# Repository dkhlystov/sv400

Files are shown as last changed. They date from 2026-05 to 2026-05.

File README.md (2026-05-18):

# SUZUKI SV400

## Личные ощущения

#### Что понравилось

- Тянет достойно - L-мотор неприхотлив к оборотам. Тяга хорошая от низов до верха.

- Легкий и сбитый - аллюминиевая рама-клетка это тема. Вес небольшой, жесткость на высоте.

- Расход в пределах 5 л.

- Небольшие размеры - плюс в междурядье.

- Звук мотора хорош.

#### Хотелось бы улучшить

- На классике после 100 км/ч ветром сдувает, на "S" возможно не так .

- Высокий центр тяжести. В движении не парит, а вот когда стоишь - мот хочет упасть.

- Карбюраторы требуют внимания (не инжектор к сожалению).

- Нет ABS. Пару раз оттормаживался до срыва - ощущения не из приятных.

## Документация

[Руководство пользователя](https://github.com/dkhlystov/sv400/tree/main/Documentation/SV650%20User%20Manual) (по большей части SV400 и SV650 соответствуют)

[Руководство по обслуживанию SV650 1998](https://github.com/dkhlystov/sv400/tree/main/Documentation/SV650%20Service%20Manual/SV650%201998) (SV400 и SV650 1998 года соответстуют)

[Руководство по обслуживанию SV650 2003](https://github.com/dkhlystov/sv400/tree/main/Documentation/SV650%20Service%20Manual/SV650%202003) (SV650 2003 года более новый, возможно есть полезная инфа)

[Каталог запчастей SV400](https://github.com/dkhlystov/sv400/tree/main/Documentation/SV400%20Cat) (OEM номера)

## Современная приборка

Свой мот взял беспробежным, но в Японии была повреждена приборка. Промониторив рынок, решил взять с алика китайскую цифровую приборку для Titan 150. [Доки на нее есть в репе](https://github.com/dkhlystov/sv400/tree/main/Dashboard%20Controller/Titan%20150).

Крепление моделировал в sketch up. Заказал в конторе по лазерной резке. Дальше болгарка, сварка, краска.

Чтобы срастить железо с приборкой сделал контроллер.

Приборка Titan 150 сделана под тросик (скорость), поэтому пришлось разобрать ее и вывести провод от датчика холла.

Дополнительно есть возможность подключить индикатор передачи (не сильно большими трудозатратами). Не занимался пока этим.

На индикатор уровня топлива кинул датчик лампы (не нашел подходящих вариантов резистивных датчиков). На данный момент датчик топлива показывает два значения 100% и 20%.

Для тех, кто решит повторить - схемы "Splan", печатная плата "Sprint Layout", код "Arduino IDE"

#### Выводы

| Обозначение | Описание |
| - | - |
| GND | Общий |
| 12V | + 12 В |
| S+ | Питание датчика скорости |
| SO | Выход скорости (на Titan 150) |
| FO | Выход датчика топлива резистивный (на Titan 150) |
| SI | Вход датчика скорости с мота |
| FIA | Вход аналогового датчика топлива (лампы) с мота |
| FID | Вход цифрового датчика топлива (не тестил, просто добавил возможность подключить) |

Контроллер сделан на базе ESP12. Тесты и настройки доступны по Wi-Fi "SV400" (точка доступа отключается после 60 сек простоя).
Для входа используется адрес http://192.168.1.1

Есть вопросы - пиши на `dkhlystov@gmail.com`

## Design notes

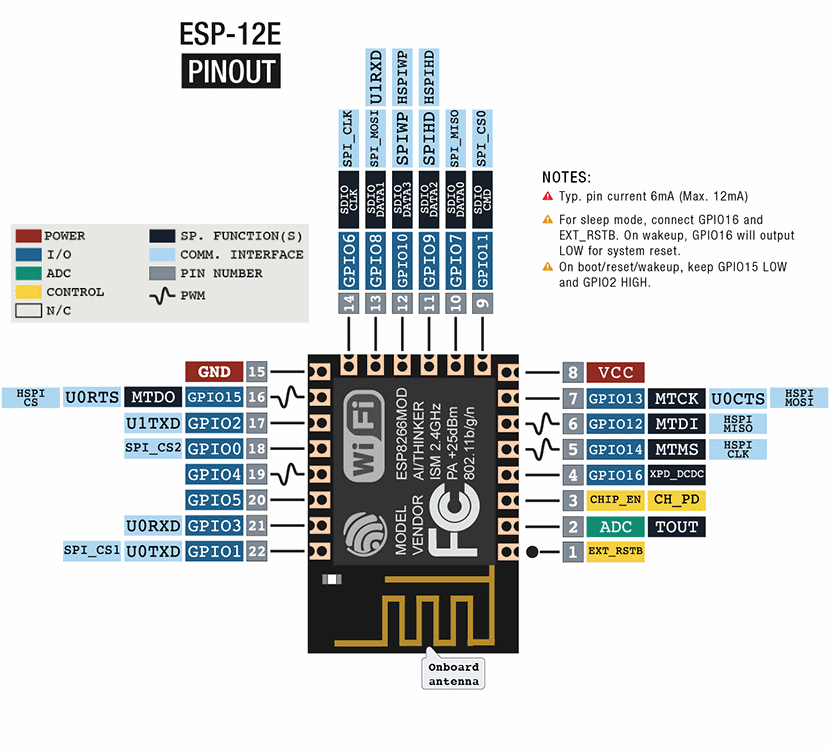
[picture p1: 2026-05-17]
Dashboard Controller/v4/tmp/62dd93cfcf3acb66be8b525c35198cde.png

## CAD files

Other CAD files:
Dashboard Controller/scheme.skp

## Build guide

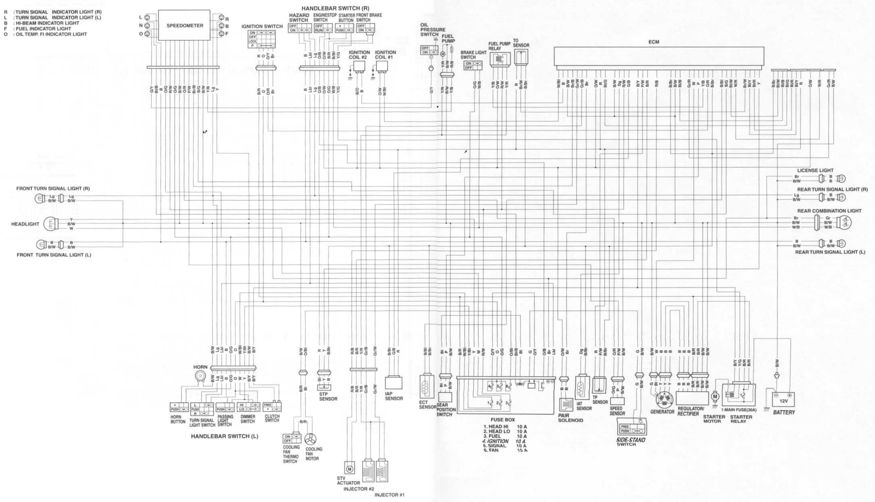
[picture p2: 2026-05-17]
Documentation/SV650 Service Manual/SV650 Wiring diagram.jpg

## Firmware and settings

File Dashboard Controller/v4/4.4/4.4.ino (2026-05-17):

#include <ArduinoJson.h>
#include <ESP8266WebServer.h>
#include <ESP8266WiFi.h>
#include <FileData.h>
#include <LittleFS.h>
#include "Dashboard.h"
#include "SpeedSensor.h"
#include "FuelSensorAnalog.h"
#include "FuelSensorDigital.h"

// === CONST ===
const int DASHBOARD_MODE_WORK = 0;
const int DASHBOARD_MODE_TEST = 1;
const int TIRE_120_60_R17 = 0;
const int TIRE_120_70_R17 = 1;
const int FUEL_SENSOR_NONE = 0;
const int FUEL_SENSOR_ANALOG = 1;
const int FUEL_SENSOR_DIGITAL = 2;

// === CONFIG ===
// 6-11 unused
// 1 TX
// 2 Buildin LED
// 3 RX
const int PIN_DASHBOARD_SPEED = 4;
const int PIN_DASHBOARD_FUEL1 = 16;
const int PIN_DASHBOARD_FUEL2 = 14;
const int PIN_DASHBOARD_FUEL3 = 12;
const int PIN_DASHBOARD_FUEL4 = 13;
const int PIN_DASHBOARD_FUEL5 = 15;
const int PIN_SPEED_SENSOR = 3;
const int PIN_FUEL_SENSOR_ANALOG_OUT = 5;
const int PIN_FUEL_SENSOR_ANALOG_IN = A0;
const int PIN_FUEL_SENSOR_DIGITAL = 1;
const int PIN_LED = 2;

const char* AP_SSID = "SV400";
const int AP_TIMEOUT = 60000; // 60s
IPAddress local_ip(192, 168, 1, 1);
IPAddress gateway(192, 168, 1, 1);
IPAddress subnet(255, 255, 255, 0);

struct Config {
  int dashboardMode = DASHBOARD_MODE_WORK;
  int dashboardTestSpeed = 0;
  int dashboardTestFuel = 0;
  int speedSensorTire = TIRE_120_60_R17;
  int fuelSensorType = FUEL_SENSOR_NONE;
  int fuelSensorAnalogThresholdLow = 500;
  int fuelSensorAnalogThresholdHigh = 500;
  int fuelSensorAnalogTarget = 20;
  int fuelSensorDigitalFullValue = 20;
  int fuelSensorDigitalEmptyValue = 10;
};
Config config;
FileData configData(&LittleFS, "/config", 'B', &config, sizeof(config));

// === VARIABLES ===
Dashboard dashboard(PIN_DASHBOARD_SPEED, PIN_DASHBOARD_FUEL1, PIN_DASHBOARD_FUEL2, PIN_DASHBOARD_FUEL3, PIN_DASHBOARD_FUEL4, PIN_DASHBOARD_FUEL5);
SpeedSensor speedSensor(PIN_SPEED_SENSOR);
FuelSensorAnalog fuelSensorAnalog(PIN_FUEL_SENSOR_ANALOG_OUT, PIN_FUEL_SENSOR_ANALOG_IN);
FuelSensorDigital fuelSensorDigital(PIN_FUEL_SENSOR_DIGITAL);

ESP8266WebServer server(80);
String serverAlert = "";

unsigned long timeLED;
unsigned long timeAP;

void setup() {
  // Buildin LED
  pinMode(PIN_LED, OUTPUT);
  digitalWrite(PIN_LED, LOW);

  // Read config
  LittleFS.begin();
  configData.read();
  applyConfig();

  // Soft AP
  WiFi.mode(WIFI_AP);
  WiFi.softAP(AP_SSID);
  WiFi.softAPConfig(local_ip, gateway, subnet);

  // Web server
  server.on("/", serverHandleIndex);
  server.on("/dashboard", serverHandleDashboard);
  server.on("/speed", serverHandleSpeed);
  server.on("/fuel", serverHandleFuel);
  server.on("/state", serverHandleState);
  server.begin();

  // Time
  timeLED = timeAP = millis();
}

void loop() {
  unsigned long time = millis();

  // Dashboard values
  if (config.dashboardMode == DASHBOARD_MODE_WORK) {
    dashboard.setSpeed(speedSensor.getValue());
    float fuel = 0;
      fuel = 0.5;
    if (config.fuelSensorType == FUEL_SENSOR_ANALOG) {
      fuel = fuelSensorAnalog.getValue();
    } else if (config.fuelSensorType == FUEL_SENSOR_DIGITAL) {
      fuel = fuelSensorDigital.getValue();
    }
    dashboard.setFuel(fuel);
  } else if (config.dashboardMode == DASHBOARD_MODE_TEST) {
    dashboard.setSpeed(config.dashboardTestSpeed);
    dashboard.setFuel(float(config.dashboardTestFuel) / 100);
  }

  // Soft AP management
  if (WiFi.getMode() == WIFI_AP) {
    if (WiFi.softAPgetStationNum() > 0) {
      timeAP = time;
    } else {
      if (timeAP + AP_TIMEOUT < time) {
        WiFi.softAPdisconnect(true);
        WiFi.mode(WIFI_OFF);
      }
    }
  }

  // Buildin LED
  if (timeLED + 50 < time) {
    if (WiFi.getMode() != WIFI_AP) {
      digitalWrite(PIN_LED, HIGH);
    }
  } else {
    digitalWrite(PIN_LED, LOW);
  }
  if (timeLED + 3000 < time) {
    timeLED = time;
  }

  // Process handlers
  dashboard.loop();
  speedSensor.loop();
  fuelSensorAnalog.loop();
  fuelSensorDigital.loop();
  server.handleClient();
  configData.tick();
}

void applyConfig() {
  // Speed sensor
  if (config.speedSensorTire == TIRE_120_60_R17) {
    speedSensor.setTireWidth(120);
    speedSensor.setTireAspectRatio(60);
    speedSensor.setTireRimSize(17);
  } else if (config.speedSensorTire == TIRE_120_70_R17) {
    speedSensor.setTireWidth(120);
    speedSensor.setTireAspectRatio(70);
    speedSensor.setTireRimSize(17);
  }

  // Fuel sensor analog
  fuelSensorAnalog.setThresholdLow(config.fuelSensorAnalogThresholdLow);
  fuelSensorAnalog.setThresholdHigh(config.fuelSensorAnalogThresholdHigh);
  fuelSensorAnalog.setTarget(float(config.fuelSensorAnalogTarget) / 100);

  // Fuel sensor digital
  fuelSensorDigital.setFullValue(config.fuelSensorDigitalFullValue);
  fuelSensorDigital.setEmptyValue(config.fuelSensorDigitalEmptyValue);
}

const char* layoutMain PROGMEM = R"=====(
  <!doctype html>
  <html lang="en">
    <head>
      <meta charset="utf-8">
      <meta name="viewport" content="width=device-width, initial-scale=1">
      <title>{title}</title>
      <style>
        * {
          box-sizing: border-box;
          font-family: sans-serif;
          font-size: 14px;        
        }
        body {
          max-width: 400px;
        }
        .btn, button {
          background: #000;
          border: 1px #000 solid;
          border-radius: 4px;
          color: #fff;
          cursor: pointer;
          display: inline-block;
          min-width: 100px;
          padding: 12px;
          text-align: center;
          text-decoration: none;
        }
        input[type=text], select {
          background: #fff;
          border: 1px #999 solid;
          border-radius: 4px;
          color: #333;
          padding: 8px;
          width: 100%;
        }
        input[type=text][disabled] {
          background: #ddd;
        }
        select {
          padding: 8px 4px;
        }
        table {
          width: 100%;
        }
        .h {
          font-size: 18px;
          font-weight: bold;
          padding: 8px 0;
        }
        .mv {
          margin: 8px 0;
        }
        td {
          white-space: nowrap;
        }
        .w100 {
          width: 100%;
        }
        .heading {
          align-items: center;
          color: #333;
          display: flex;
          text-decoration: none;
        }
        svg {
          display: block;
        }
        .title {
          font-size: 42px;
          font-weight: 300;
          line-height: 1;
          margin-left: 24px;
        }
        .alert {
          background: #ddffe3;
          border: 1px solid #3b8247;
          border-radius: 4px;
          color: #3b8247;
          padding: 8px;
        }
        .hidden {
          display: none;
        }
      </style>
    </head>
    <body>
      <a href="/" class="heading">
        <div class="logo">
          <svg x="0px" y="0px" width="50" height="50" viewBox="0 0 50 50"><linearGradient id="fill" x1="40%" y1="40%" x2="70%" 
          y2="70%"><stop offset="0" stop-color="#aaa" /><stop offset="1" 
          stop-color="#555" /></linearGradient><path d="M 36.277344 
          23.632813 C 36.769531 23.671875 37.269531 23.691406 37.785156 23.691406 C 
          40.976563 23.691406 45.308594 22.953125 47.8125 19.4375 C 48.132813 18.988281 
          48.03125 18.371094 47.585938 18.046875 L 25.660156 2.1875 C 25.273438 1.90625 
          24.738281 1.941406 24.390625 2.273438 C 20.722656 5.734375 7.359375 12.917969 
          2.710938 14.519531 C 2.359375 14.636719 2.105469 14.941406 2.046875 15.304688 
          C 1.996094 15.636719 2.117188 15.964844 2.359375 16.1875 L 30.417969 
          36.070313 L 28.632813 37.257813 L 12.960938 26.152344 C 12.484375 26.097656 
          11.992188 26.066406 11.488281 26.066406 C 8.160156 26.066406 5.078125 
          27.339844 2.328125 29.84375 C 2.105469 30.042969 1.988281 30.332031 2 
          30.628906 C 2.015625 30.925781 2.160156 31.203125 2.398438 31.382813 L 
          24.289063 47.796875 C 24.46875 47.933594 24.679688 48 24.890625 48 C 
          25.128906 48 25.367188 47.910156 25.558594 47.742188 C 29.433594 44.246094 
          42.121094 36.667969 46.449219 35.265625 C 46.804688 35.148438 47.066406 
          34.847656 47.128906 34.480469 C 47.1875 34.109375 47.039063 33.738281 
          46.742188 33.515625 L 46.410156 33.265625 L 19.4375 14.152344 L 21.222656 
          12.964844 Z" fill="url(#fill)"></path></svg>
        </div>
        <div class="title">SV400</div>
      </a>
      {content}
    </body>
  </html>
)=====";

const char* templateIndex PROGMEM = R"=====(
  <div>
    <div class="mv">
      <a href="/dashboard" class="btn w100">Приборная панель</a>
    </div>
    <div class="mv">
      <a href="/speed" class="btn w100">Датчик скорости</a>
    </div>
    <div class="mv">
      <a href="/fuel" class="btn w100">Датчик топлива</a>
    </div>
    <div class="mv">
      <p>https://github.com/dkhlystov/sv400</p>
    </div>
  </div>
)=====";

const char* templateDashboard PROGMEM = R"=====(
  {alert}
  <form method="post">
    <table><tbody>
      <tr><td colspan="2" class="h">Приборная панель</td></tr>
      <tr><td>Режим:</td><td><select name="mode" id="mode" onchange="modeChange()">{mode}</select></td></tr>
      <tr class="mode_work"><td>Скорость (км/ч):</td><td><input type="text" name="speed" id="speed" value="{speed}" disabled></td></tr>
      <tr class="mode_work"><td>Топливо (%):</td><td><input type="text" name="fuel" id="fuel" value="{fuel}" disabled></td></tr>
      <tr class="mode_test"><td>Скорость (км/ч):</td><td><input type="text" name="test_speed" id="speed" value="{test_speed}"></td></tr>
      <tr class="mode_test"><td>Топливо (%):</td><td><input type="text" name="test_fuel" id="fuel" value="{test_fuel}"></td></tr>
    </tbody></table>
    <div class="mv">
      <button type="submit">Сохранить</button>
      <a href="/" class="btn">Отмена</a>
    </div>
  </form>
  <script type="text/javascript">
    function modeChange() {
      const v = document.getElementById('mode').value;
      let work = document.querySelectorAll('.mode_work');
      let test = document.querySelectorAll('.mode_test');
      if (v == 0) {
        work.forEach(el => {el.classList.remove('hidden')});
        test.forEach(el => {el.classList.add('hidden')});
      } else {
        work.forEach(el => {el.classList.add('hidden')});
        test.forEach(el => {el.classList.remove('hidden')});
      }
    }
    modeChange();
    setInterval(function() {
      const x = new XMLHttpRequest();
      x.open("GET", "/state", false);
      x.send(null);
      const state = JSON.parse(x.responseText);
      document.getElementById('speed').value = state.dashboardSpeed;
      document.getElementById('fuel').value = state.dashboardFuel;
      document.getElementById('digital_raw_data').value = state.fuelSensorDigitalRawData;
    }, 500);
  </script>
)=====";

const char* templateSpeed PROGMEM = R"=====(
  {alert}
  <form method="post">
    <table><tbody>
      <tr><td colspan="2" class="h">Датчик скорости</td></tr>
      <tr><td>Текущая скорость:</td><td><input type="text" id="speed" value="{speed}" disabled></td></tr>
      <tr><td>Размер шины:</td><td><select name="tire">{tire}</select></td></tr>
    </tbody></table>
    <div class="mv">
      <button type="submit">Сохранить</button>
      <a href="/" class="btn">Отмена</a>
    </div>
  </form>
  <script type="text/javascript">
    setInterval(function() {
      const x = new XMLHttpRequest();
      x.open("GET", "/state", false);
      x.send(null);
      const state = JSON.parse(x.responseText);
      document.getElementById('speed').value = state.speedSensorValue;
    }, 500);
  </script>
)=====";

const char* templateFuel PROGMEM = R"=====(
  {alert}
  <form method="post">
    <table><tbody>
      <tr><td colspan="2" class="h">Датчик топлива</td></tr>
      <tr><td>Тип:</td><td><select name="type">{type}</select></td></tr>
      <tr><td colspan="2" class="h">Аналоговый</td></tr>
      <tr><td>Текущие показания:</td><td><input type="text" id="analog_raw_data" value="{analog_raw_data}" disabled></td></tr>
      <tr><td>Верхний порог:</td><td><input type="text" name="analog_threshold_high" value="{analog_threshold_high}"></td></tr>
      <tr><td>Нижний порог:</td><td><input type="text" name="analog_threshold_low" value="{analog_threshold_low}"></td></tr>
      <tr><td>Текущее состояние:</td><td><input type="text" id="analog_is_on" value="{analog_is_on}" disabled></td></tr>
      <tr><td>Низкий уровень (%):</td><td><input type="text" name="analog_target" value="{analog_target}"></td></tr>
      <tr><td colspan="2" class="h">Цифровой</td></tr>
      <tr><td>Текущие показания:</td><td><input type="text" id="digital_raw_data" value="{digital_raw_data}" disabled></td></tr>
      <tr><td>Полный бак:</td><td><input type="text" name="digital_full" value="{digital_full}"></td></tr>
      <tr><td>Пустой бак:</td><td><input type="text" name="digital_empty" value="{digital_empty}"></td></tr>
    </tbody></table>
    <div class="mv">
      <button type="submit">Сохранить</button>
      <a href="/" class="btn">Отмена</a>
    </div>
  </form>
  <script type="text/javascript">
    setInterval(function() {
      const x = new XMLHttpRequest();
      x.open("GET", "/state", false);
      x.send(null);
      const state = JSON.parse(x.responseText);
      document.getElementById('analog_raw_data').value = state.fuelSensorAnalogRawData;
      document.getElementById('analog_is_on').value = state.fuelSensorAnalogIsOn ? "ON" : "OFF";
      document.getElementById('digital_raw_data').value = state.fuelSensorDigitalRawData;
    }, 500);
  </script>
)=====";

String htmlOption(const String &value, const String &content, const boolean &selected) {
  String s = "";
  if (selected) {
    s = " selected";
  }
  return "<option value=\"" + value + "\"" + s + ">" + content + "</option>";
}

void serverHandleIndex() {
  String layout = String(layoutMain);
  layout.replace("{title}", "SV400");
  layout.replace("{content}", templateIndex);

  server.send(200, "text/html", layout);
}

void serverHandleDashboard() {
  if (server.hasArg("mode")) {
    config.dashboardMode = server.arg("mode").toInt();
    config.dashboardTestSpeed = server.arg("test_speed").toInt();
    config.dashboardTestFuel = server.arg("test_fuel").toInt();
    configData.update();
    applyConfig();

    serverAlert = "Изменения успешно сохранены.";
    server.sendHeader("Location", "/dashboard");
    server.send(302);
    return;
  }

  String content = String(templateDashboard);
  String options = htmlOption(String(DASHBOARD_MODE_WORK), "Работа", config.dashboardMode == DASHBOARD_MODE_WORK);
  options += htmlOption(String(DASHBOARD_MODE_TEST), "Тестирование", config.dashboardMode == DASHBOARD_MODE_TEST);
  content.replace("{mode}", options);
  content.replace("{speed}", String(dashboard.getSpeed()));
  content.replace("{fuel}", String(dashboard.getFuel() * 100, 0));
  content.replace("{test_speed}", String(config.dashboardTestSpeed));
  content.replace("{test_fuel}", String(config.dashboardTestFuel));
  if (serverAlert != "") {
    serverAlert = "<div class=\"alert\">" + serverAlert + "</div>";
  }
  content.replace("{alert}", serverAlert);
  serverAlert = "";

  String layout = String(layoutMain);
  layout.replace("{title}", "SV400 - Приборная панель");
  layout.replace("{content}", content);

  server.send(200, "text/html", layout);
}

void serverHandleSpeed() {
  if (server.hasArg("tire")) {
    config.speedSensorTire = server.arg("tire").toInt();
    configData.update();
    applyConfig();

    serverAlert = "Изменения успешно сохранены.";
    server.sendHeader("Location", "/speed");
    server.send(302);
    return;
  }

  String content = String(templateSpeed);
  content.replace("{speed}", String(speedSensor.getValue()));
  String options = htmlOption(String(TIRE_120_60_R17), "120/60 R17", config.speedSensorTire == TIRE_120_60_R17);
  options += htmlOption(String(TIRE_120_70_R17), "120/70 R17", config.speedSensorTire == TIRE_120_70_R17);
  content.replace("{tire}", options);
  if (serverAlert != "") {
    serverAlert = "<div class=\"alert\">" + serverAlert + "</div>";
  }
  content.replace("{alert}", serverAlert);
  serverAlert = "";

  String layout = String(layoutMain);
  layout.replace("{title}", "SV400 - Датчик скорости");
  layout.replace("{content}", content);

  server.send(200, "text/html", layout);
}

void serverHandleFuel() {
  if (server.hasArg("type")) {
    config.fuelSensorType = server.arg("type").toInt();
    config.fuelSensorAnalogThresholdLow = server.arg("analog_threshold_low").toInt();
    config.fuelSensorAnalogThresholdHigh = server.arg("analog_threshold_high").toInt();
    config.fuelSensorAnalogTarget = server.arg("analog_target").toInt();
    config.fuelSensorDigitalFullValue = server.arg("digital_full").toInt();
    config.fuelSensorDigitalEmptyValue = server.arg("digital_empty").toInt();
    configData.update();
    applyConfig();

    serverAlert = "Изменения успешно сохранены.";
    server.sendHeader("Location", "/fuel");
    server.send(302);
    return;
  }

  String content = String(templateFuel);
  String options = htmlOption(String(FUEL_SENSOR_NONE), "Нет", config.fuelSensorType == FUEL_SENSOR_NONE);
  options += htmlOption(String(FUEL_SENSOR_ANALOG), "Аналоговый", config.fuelSensorType == FUEL_SENSOR_ANALOG);
  options += htmlOption(String(FUEL_SENSOR_DIGITAL), "Цифровой", config.fuelSensorType == FUEL_SENSOR_DIGITAL);
  content.replace("{type}", options);
  content.replace("{analog_raw_data}", String(fuelSensorAnalog.getRawData()));
  content.replace("{analog_threshold_low}", String(config.fuelSensorAnalogThresholdLow));
  content.replace("{analog_threshold_high}", String(config.fuelSensorAnalogThresholdHigh));
  content.replace("{analog_is_on}", fuelSensorAnalog.isOn() ? "ON" : "OFF");
  content.replace("{analog_target}", String(config.fuelSensorAnalogTarget));
  content.replace("{digital_raw_data}", String(fuelSensorDigital.getRawData()));
  content.replace("{digital_full}", String(config.fuelSensorDigitalFullValue));
  content.replace("{digital_empty}", String(config.fuelSensorDigitalEmptyValue));
  if (serverAlert != "") {
    serverAlert = "<div class=\"alert\">" + serverAlert + "</div>";
  }
  content.replace("{alert}", serverAlert);
  serverAlert = "";

  String layout = String(layoutMain);
  layout.replace("{title}", "SV400 - Датчик топлива");
  layout.replace("{content}", content);

  server.send(200, "text/html", layout);
}

void serverHandleState() {
  JsonDocument json;
  json["dashboardSpeed"] = dashboard.getSpeed();
  json["dashboardFuel"] = round(dashboard.getFuel() * 100);
  json["speedSensorValue"] = speedSensor.getValue();
  json["fuelSensorAnalogRawData"] = fuelSensorAnalog.getRawData();
  json["fuelSensorAnalogIsOn"] = fuelSensorAnalog.isOn();
  json["fuelSensorDigitalRawData"] = fuelSensorDigital.getRawData();
  
  String content;
  serializeJson(json, content);
  server.send(200, "application/json", content);
}

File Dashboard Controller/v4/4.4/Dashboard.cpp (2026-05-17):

#include "Arduino.h"
#include "Dashboard.h"

Dashboard::Dashboard(int speedPin, int fuelPin1, int fuelPin2, int fuelPin3, int fuelPin4, int fuelPin5) {
  // Defaults
  _speedRate = 0.754;
  _speed = 0;
  _fuel = 0.0;

  // Init
  pinMode(speedPin, OUTPUT);
  pinMode(fuelPin1, OUTPUT);
  pinMode(fuelPin2, OUTPUT);
  pinMode(fuelPin3, OUTPUT);
  pinMode(fuelPin4, OUTPUT);
  pinMode(fuelPin5, OUTPUT);
  digitalWrite(speedPin, LOW);
  digitalWrite(fuelPin1, LOW);
  digitalWrite(fuelPin2, LOW);
  digitalWrite(fuelPin3, LOW);
  digitalWrite(fuelPin4, LOW);
  digitalWrite(fuelPin5, LOW);
  _speedPin = speedPin;
  _fuelPin1 = fuelPin1;
  _fuelPin2 = fuelPin2;
  _fuelPin3 = fuelPin3;
  _fuelPin4 = fuelPin4;
  _fuelPin5 = fuelPin5;

  _speedPinValue = 0;
  _speedTime = micros();
}

int Dashboard::getSpeed() {
  return _speed;
}

void Dashboard::setSpeed(int value) {
  if (value < 0) {
    value = 0;
  } else if (value > 300) {
    value = 300;
  }
  if (_speed != value) {
    _speed = value;
  }
}

float Dashboard::getFuel() {
  return _fuel;
}

void Dashboard::setFuel(float value) {
  if (value < 0) {
    value = 0;
  } else if (value > 1) {
    value = 1;
  }
  if (_fuel != value) {
    _fuel = value;
    updateFuelLevel();
  }
}

void Dashboard::updateFuelLevel() {
  float level = round(_fuel * 5);
  if (level > 0) digitalWrite(_fuelPin1, HIGH);
  else digitalWrite(_fuelPin1, LOW);
  if (level > 1) digitalWrite(_fuelPin2, HIGH);
  else digitalWrite(_fuelPin2, LOW);
  if (level > 2) digitalWrite(_fuelPin3, HIGH);
  else digitalWrite(_fuelPin3, LOW);
  if (level > 3) digitalWrite(_fuelPin4, HIGH);
  else digitalWrite(_fuelPin4, LOW);
  if (level > 4) digitalWrite(_fuelPin5, HIGH);
  else digitalWrite(_fuelPin5, LOW);
}

void Dashboard::loop() {
  unsigned long time = micros();
  // Dashboard out
  if (_speed > 0) {
    // Calc period
    unsigned long period = 1000000 / (_speed * _speedRate) / 2;
    // Check timestemp
    if (_speedTime + period < time) {
      _speedTime = time;
      _speedPinValue = 1 - _speedPinValue;
      digitalWrite(_speedPin, _speedPinValue);
    }
  }
}

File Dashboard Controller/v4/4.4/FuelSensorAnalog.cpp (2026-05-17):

#include "Arduino.h"
#include "FuelSensorAnalog.h"

FuelSensorAnalog::FuelSensorAnalog(int pinOut, int pinIn) {
  // Defaults
  _on = false;
  _thresholdLow = 500;
  _thresholdHigh = 500;
  _target = 0.2;

  _duration = 500;

  // Init
  pinMode(pinOut, OUTPUT);
  pinMode(pinIn, INPUT);
  _pinOut = pinOut;
  _pinIn = pinIn;
  digitalWrite(_pinOut, LOW);
  _time = millis();
}

boolean FuelSensorAnalog::isOn() {
  return _on;
}

int FuelSensorAnalog::getRawData() {
  return _rawData;
}

int FuelSensorAnalog::getThresholdLow() {
  return _thresholdLow;
}

void FuelSensorAnalog::setThresholdLow(int value) {
  if (value < 0) {
    value = 0;
  } else if (value > 1023) {
    value = 1023;
  }
  if (_thresholdLow != value) {
    _thresholdLow = value;
    if (_thresholdHigh < value) {
      _thresholdHigh = value;
    }
  }
}

int FuelSensorAnalog::getThresholdHigh() {
  return _thresholdHigh;
}

void FuelSensorAnalog::setThresholdHigh(int value) {
  if (value < 0) {
    value = 0;
  } else if (value > 1023) {
    value = 1023;
  }
  if (_thresholdHigh != value) {
    _thresholdHigh = value;
    if (_thresholdLow > value) {
      _thresholdLow = value;
    }
  }
}

float FuelSensorAnalog::getTarget() {
  return _target;
}

void FuelSensorAnalog::setTarget(float value) {
  if (value < 0) {
    value = 0;
  } else if (value > 1) {
    value = 1;
  }
  if (_target != value) {
    _target = value;
  }
}

float FuelSensorAnalog::getValue() {
  return _on ? _target : 1;
}

void FuelSensorAnalog::loop() {
  if (_time + _duration < millis()) {
    _time = millis();

    digitalWrite(_pinOut, HIGH);
    _rawData = analogRead(_pinIn);
    if (_rawData < _thresholdLow) {
      digitalWrite(_pinOut, LOW);
    }

    if (_on) {
      if (_rawData > _thresholdHigh) {
        _on = false;
      }
    } else {
      if (_rawData < _thresholdLow) {
        _on = true;
      }
    }
  }
}
